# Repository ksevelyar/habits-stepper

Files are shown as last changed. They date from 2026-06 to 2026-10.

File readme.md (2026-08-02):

# Habits Stepper
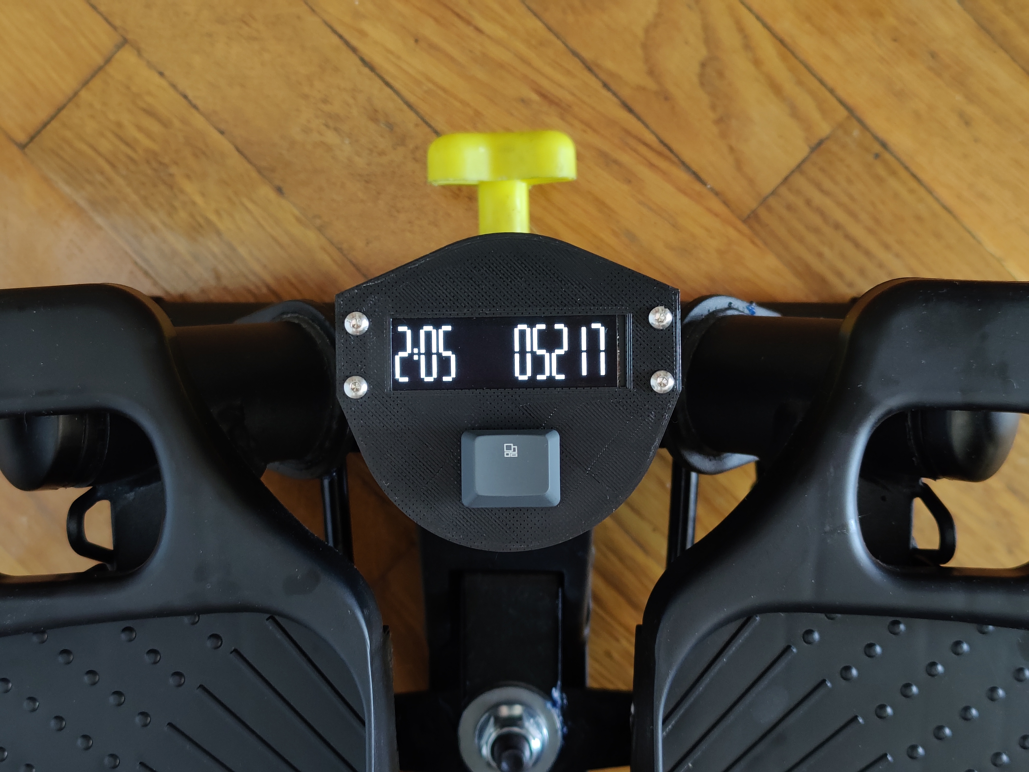
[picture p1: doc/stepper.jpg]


## Why
Automatically tracks stepping sessions without requiring any button presses to start or reset workouts. Time is synced via NTP so new day and week boundaries are handled automatically — no need to remember to reset counts on Monday. Just start stepping and sessions are tracked correctly.

## Overview
* auto-track stepping sessions, time-synced via NTP with a compile-time IANA timezone
* async embassy runtime; display updates only on input events via channels
* deep sleep after 90s of inactivity; 18650 battery gives ~2 weeks without charging
* firmware upload (probe-rs), defmt logs (RTT), and battery charging over a single USB-C port
* ring buffer in NOR flash (512 sessions); data survives deep sleep and reboots
* on-MCU tests via embedded_test
* 3D-printed case (OpenSCAD) with SH1122 256x64 OLED display

## Build & Flash
```
nix develop

cargo run --release
    Finished `release` profile [optimized + debuginfo] target(s) in 0.10s
     Running `probe-rs run --chip=esp32c3 --preverify --always-print-stacktrace --no-location target/riscv32imc-unknown-none-elf/release/habits-stepper`
    Verifying ✔ 100% [####################] 360.25 KiB @  74.20 KiB/s (took 5s)           Finished in 5.09s
03:00:00 [INFO ] init: embassy initialized
03:00:00 [INFO ] storage: flash capacity: 4194304B
03:00:00 [INFO ] storage: loaded 18 sessions from flash (head=18)
13:57:03 [INFO ] time: rtc seeded: Europe/Moscow 2026-06-13 13:57:03
13:57:03 [INFO ] wifi: connecting to "fellowship-of-the-ring-2"
13:57:04 [INFO ] wifi: connected to "fellowship-of-the-ring-2"
13:57:18 [INFO ] time: synced (+4s)
13:57:18 [INFO ] time: Europe/Moscow 2026-06-13 13:57:18
13:57:18 [INFO ] time: waiting 90s for inactivity
13:57:26 [INFO ] input: reed closed
13:57:26 [INFO ] time: activity before timeout, resetting
13:57:26 [INFO ] time: waiting 90s for inactivity
13:57:26 [INFO ] display: session update: today=50min(1036steps) week=50min
13:57:29 [INFO ] input: reed closed
13:57:29 [INFO ] time: activity before timeout, resetting
13:57:29 [INFO ] time: waiting 90s for inactivity
13:57:29 [INFO ] display: session update: today=50min(1037steps) week=50min
```

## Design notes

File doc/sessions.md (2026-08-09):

# Sessions
## Overview
Session task receives events from user_input, manages
session state, and sends session events to display.

## Input
* `StepDetected`: creates or prolongs current session
* `HistoryPressed`: switches display to SessionHistory view
* `HistoryReleased`: switches display back to SessionUpdate view

## Output
* `SessionEvent::Update(WeekTotals { minutes, steps })`: sent on step or history toggle
* `SessionEvent::History(WeekTotals { minutes, steps })`: sent on HistoryPressed

## Permanent storage
* Load sessions from permanent storage, log error on failure
* On load, log the number of loaded sessions
* On session end, save to permanent storage, signal today and yesterday totals for the backend, and log
* Backend replaces the value for a given date, so lost or failed posts self-heal on the next session end
* esp32c3 NOR flash wear should be minimized
* See [sessions/storage.md](sessions/storage.md) for the storage design

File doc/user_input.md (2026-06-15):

# User input

## Reed switch
A single reed switch on the right side captures both left and right steps. The pedals work in opposition: pressing the left pedal raises the right pedal, opening the reed and counting a left step; pressing the right pedal closes the reed and counts a right step. Both edges are counted as `StepDetected`.

## History button
When pressed the display shows the previous week's totals; when
released it returns to the current week.

## Boot
On boot, user_input sends `HistoryReleased` so the display shows data immediately.

## Sleep
* mcu wakes up from deep sleep via reed switch or history button
* deep sleep after 90s of inactivity
* the reed current level is sampled before sleep. Wake-up is set for the opposite level. This way the chip wakes on the first reed change whether the pedal was pressed or released at sleep time.

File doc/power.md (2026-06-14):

## Power
* Samsung ICR18650-26J 2600mAh
* tp4057
* mcp1700

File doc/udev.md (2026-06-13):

# udev setup for ESP32-C3 with probe-rs

```nix
services.udev.extraRules = ''
  SUBSYSTEM=="usb", ATTR{idVendor}=="303a", ATTR{idProduct}=="1001", MODE="0660", GROUP="dialout"
'';
```

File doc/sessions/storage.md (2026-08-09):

# Session Storage

`FlashRing` stores completed sessions in two 4096-byte NOR flash sectors.

| Sector | Address |
| --- | --- |
| 0 | `0x3F0000` |
| 1 | `0x3F1000` |

Each sector contains 256 slots. Each slot is 16 bytes:

| Offset | Size | Field |
| --- | --- | --- |
| 0 | 4 | Start epoch |
| 4 | 4 | End epoch |
| 8 | 4 | Steps |
| 12 | 4 | Unused |

Fields use little-endian encoding. An erased start epoch of `0xFFFF_FFFF` marks an empty slot.

On startup, storage scans the start epochs, counts occupied slots, and places the write position at the first empty slot. Sessions are returned from oldest to newest.

When 511 sessions are stored, storage erases the sector containing the oldest sessions before writing the next session. This removes 256 sessions.

Flash read, write, and erase failures are logged. Operations continue after failure.

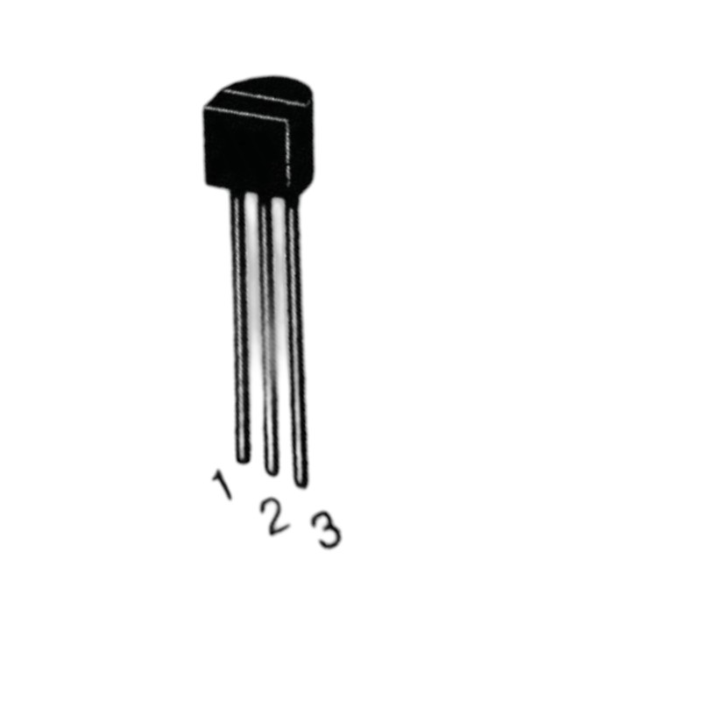
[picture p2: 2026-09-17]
doc/mcp1700.jpg

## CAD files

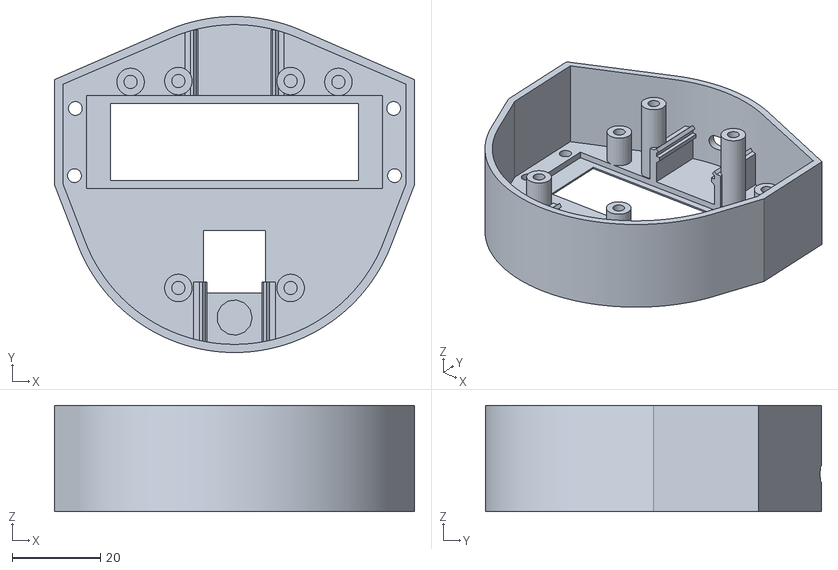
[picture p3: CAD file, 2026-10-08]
case/case.stl
81.5 x 76.0 x 24.0

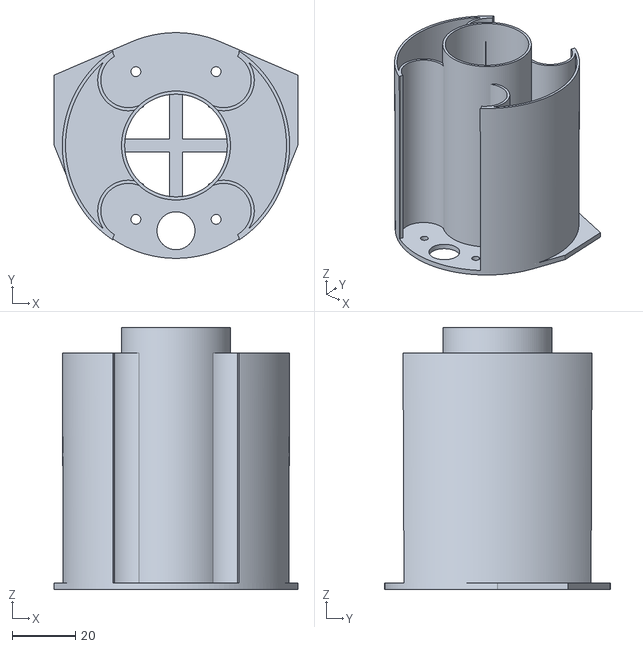
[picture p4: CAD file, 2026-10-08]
case/battery-holder.stl
77.2 x 71.5 x 83.0

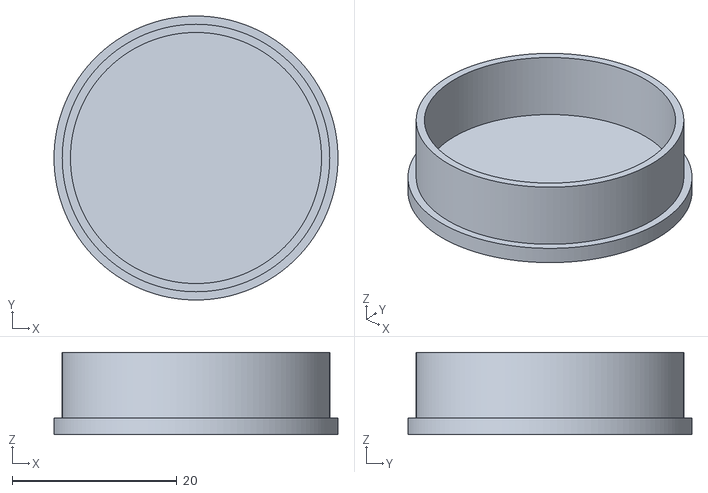
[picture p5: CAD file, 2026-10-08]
case/battery-cap.stl
34.5 x 34.5 x 10.0

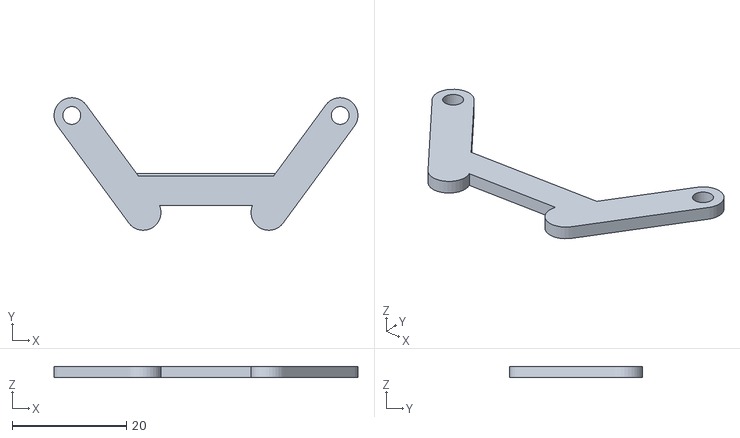
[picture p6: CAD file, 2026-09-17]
case/mcu-stopper.stl
53.2 x 23.2 x 2.00

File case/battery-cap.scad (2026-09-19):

include <mixin.scad>;

battery_cap_height = 8;

difference() {
  union() {
    translate([0, 0, 0]) cylinder(h=battery_cap_height + wall, d=battery_slot_diameter, center=false, $fn=128);
    translate([0, 0, 0]) cylinder(h=wall, d=battery_slot_diameter + 2, center=false, $fn=128);
  }

  translate([0, 0, wall]) cylinder(h=100, d=battery_slot_diameter - 2, center=false, $fn=128);
}

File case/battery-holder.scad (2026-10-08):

include <mixin.scad>;

height = 85;
connector_inner_diameter = 17.4;
mounting_hole_diameter = 3.12;

module walls() {
  difference() {
    translate([0, 0, wall]) cylinder(h=height - 12, d1=diameter - 0.5, d2=diameter, $fn=256);
    translate([0, 0, -overcut]) cylinder(h=height * 2, d=diameter - wall, $fn=256);

    translate([-20, -40, 0]) cube(size=[40, 100, height + overcut], center=false);
  }

  difference() {
    union() {
      translate([15.1, -20.7, 0]) rotate([0, 0, -60]) walls_connector();

      translate([15.1, 20.7, 0]) rotate([0, 0, -120]) walls_connector();
      translate([-15.1, 20.7, 0]) rotate([0, 0, 120]) walls_connector();
      translate([-15.1, -20.7, 0]) rotate([0, 0, 60]) walls_connector();
    }
  }
}

module walls_connector() {
  difference() {
    translate([0, 0, wall]) cylinder(h=height - 12, d=connector_inner_diameter + wall, $fn=256);
    translate([0, 0, -overcut]) cylinder(h=height * 2, d=connector_inner_diameter, $fn=256);

    translate([-(connector_inner_diameter + wall) / 2, -connector_inner_diameter, 0])
      cube([connector_inner_diameter + wall, connector_inner_diameter, height + overcut], center=false);
  }
}

module battery() {
  difference() {
    union() {
      difference() {
        hull() {
          length = display_length + 0.2;
          width = display_pcb_width + 3.1;
          translate([-length / 2, 0, 0]) cube(size=[length, width, wall]);

          translate([0, 0, 0]) cylinder(h=wall, d=diameter - 0.5, $fn=128);
        }

        translate([0, -27, -1]) cylinder(h=wall * 2, d=12, $fn=128);
      }
      translate([0, 0, 0]) cylinder(h=height - wall, d=battery_slot_diameter + 2, center=false, $fn=128);
    }

    translate([0, 0, -overcut]) cylinder(h=height + overcut, d=battery_slot_diameter, center=false, $fn=128);

    mounting_holes();
  }
}

module mounting_holes() {
  translate([12.7, -23.4, -overcut]) cylinder(h=wall * 2, d=mounting_hole_diameter, $fn=32);
  translate([-12.7, -23.4, -overcut]) cylinder(h=wall * 2, d=mounting_hole_diameter, $fn=32);
  translate([12.7, 23.4, -overcut]) cylinder(h=wall * 2, d=mounting_hole_diameter, $fn=32);
  translate([-12.7, 23.4, -overcut]) cylinder(h=wall * 2, d=mounting_hole_diameter, $fn=32);
}

module cross() {
  translate([-wall, -20, 0]) cube([wall*2, 40, wall]);
  translate([-20, -wall, 0]) cube([40, wall*2, wall]);
}

cross();

battery();
walls();

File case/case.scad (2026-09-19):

include <mixin.scad>;

height = 24;

module charger_led_cutout() {
  translate([0, -30.1, 0.2]) cylinder(h=wall, d=8);
}

module display_cutout() {
  display_slot_cutout();
  display_window_cutout();
}

module mounts() {
  translate([12.7, -23.4, 0]) leg(height - wall);
  translate([-12.7, -23.4, 0]) leg(height - wall);

  translate([12.7, 23.4, 0]) leg(height - wall);
  translate([-12.7, 23.4, 0]) leg(height - wall);

  translate([display_length / 2 - 15, display_pcb_width + 4, 0]) leg(10);
  translate([-display_length / 2 + 15, display_pcb_width + 4, 0]) leg(10);
}

difference() {
  union() {
    display();
    esp32c3_mini_rails();
    tp4057_rails();
    mounts();
  }

  type_c_cutout();
  button_cutout();
  charger_led_cutout();
  display_cutout();

  translate([display_length / 2 - 2.3, 2, -overcut]) cylinder(h=wall * 2, d=3.12, $fn=64, center=false);
  translate([-display_length / 2 + 2.3, 2, -overcut]) cylinder(h=wall * 2, d=3.12, $fn=64, center=false);
  translate([display_length / 2 - 2.5, display_pcb_width - 2, -overcut]) cylinder(h=wall * 2, d=3.12, $fn=64, center=false);
  translate([-display_length / 2 + 2.5, display_pcb_width - 2, -overcut]) cylinder(h=wall * 2, d=3.12, $fn=64, center=false);
}

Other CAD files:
case/mcu-stopper.scad
case/mixin.scad

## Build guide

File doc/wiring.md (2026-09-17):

# Wiring

## charging (tp4057)
5v from esp32 to in+
gnd from esp32 to in-

bat- to 18650-
bat+ to 18650+

out- to gnd from esp32
out+ - mcp1700 1 - esp32 3.3v

## mcp1700
1 - gnd
2 - tp4057 out+
3 - esp32 3.3v

## display sh1122, spi
gnd - gnd
vdd - 3v3
scl - gpio5
sda - gpio6
rst - gpio7
dc  - gpio9
cs  - gpio10

## buttons
reed - gpio1 + gnd
history - gpio2 + gnd

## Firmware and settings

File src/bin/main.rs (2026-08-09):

#![no_std]
#![no_main]

use esp_alloc as _;
use esp_hal::{
    clock::CpuClock,
    gpio::{Input, InputConfig, Level, Output, OutputConfig, Pull},
    rtc_cntl::Rtc,
    spi::Mode,
    spi::master::{Config as SpiConfig, Spi},
    time::Rate,
    timer::timg::TimerGroup,
};
use habits_stepper::sessions::FlashMutex;
use habits_stepper::sessions::storage;
use habits_stepper::{display, sessions, sync, time, user_input, wifi};
use panic_rtt_target as _;

use defmt::info;
use embassy_executor::Spawner;
use embassy_sync::mutex::Mutex;
use embassy_time::{Duration, Timer};
use static_cell::StaticCell;

extern crate alloc;

esp_bootloader_esp_idf::esp_app_desc!();

#[esp_rtos::main]
async fn main(spawner: Spawner) -> ! {
    rtt_target::rtt_init_defmt!();

    let config = esp_hal::Config::default().with_cpu_clock(CpuClock::max());
    let peripherals = esp_hal::init(config);
    let rtc = Rtc::new(peripherals.LPWR);

    esp_alloc::heap_allocator!(#[esp_hal::ram(reclaimed)] size: 66320);

    let timg0 = TimerGroup::new(peripherals.TIMG0);
    let sw_interrupt =
        esp_hal::interrupt::software::SoftwareInterruptControl::new(peripherals.SW_INTERRUPT);
    esp_rtos::start(timg0.timer0, sw_interrupt.software_interrupt0);
    info!("init: embassy initialized");

    let (controller, stack, runner) = wifi::init(peripherals.WIFI).await;

    spawner.spawn(wifi::connection(controller).unwrap());
    spawner.spawn(wifi::net_task(runner).unwrap());
    let rtc = time::RTC.init(Mutex::new(rtc));
    spawner.spawn(time::ntp_task(stack, rtc).unwrap());
    spawner.spawn(time::sleep_task(rtc).unwrap());
    spawner.spawn(sync::sync_task(stack).unwrap());
    let display_spi = Spi::new(
        peripherals.SPI2,
        SpiConfig::default()
            .with_frequency(Rate::from_mhz(4))
            .with_mode(Mode::_0),
    )
    .unwrap()
    .with_sck(peripherals.GPIO5)
    .with_mosi(peripherals.GPIO6);

    let display_cs = Output::new(peripherals.GPIO10, Level::High, OutputConfig::default());
    let display_dc = Output::new(peripherals.GPIO9, Level::Low, OutputConfig::default());
    let display_rst = Output::new(peripherals.GPIO7, Level::High, OutputConfig::default());

    let reed = Input::new(
        peripherals.GPIO1,
        InputConfig::default().with_pull(Pull::Up),
    );
    let history = Input::new(
        peripherals.GPIO2,
        InputConfig::default().with_pull(Pull::Up),
    );

    spawner.spawn(user_input::reed_task(reed).unwrap());
    spawner.spawn(user_input::history_task(history).unwrap());
    spawner.spawn(display::display_task(display_spi, display_cs, display_dc, display_rst).unwrap());
    static FLASH_RING: StaticCell<FlashMutex> = StaticCell::new();
    let flash_mutex = FLASH_RING.init(Mutex::new(storage::FlashRing::new(peripherals.FLASH)));

    spawner.spawn(sessions::session_task(flash_mutex).unwrap());

    loop {
        Timer::after(Duration::from_secs(3600)).await;
    }
}

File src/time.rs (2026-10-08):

use core::net::{IpAddr, SocketAddr};
use core::sync::atomic::{AtomicU32, Ordering};
use embassy_time::with_timeout;
use esp_hal::gpio::RtcPinWithResistors;
use esp_hal::peripherals::GPIO;
use esp_hal::rtc_cntl::sleep::{RtcioWakeupSource, WakeupLevel};

use defmt::{error, info, warn};
use embassy_net::{
    Stack,
    dns::DnsQueryType,
    udp::{PacketMetadata, UdpSocket},
};
use embassy_sync::blocking_mutex::raw::CriticalSectionRawMutex;
use embassy_sync::mutex::Mutex;
use embassy_time::{Duration, Instant, Timer};

use crate::user_input::ACTIVITY;
use esp_hal::rtc_cntl::Rtc;
use jiff::Timestamp;
use jiff::civil::Weekday;
use static_cell::StaticCell;

include!(concat!(env!("OUT_DIR"), "/timezone.rs"));

use sntpc::{NtpContext, NtpTimestampGenerator, get_time};
use sntpc_net_embassy::UdpSocketWrapper;

const NTP_SERVER: &str = "pool.ntp.org";
const MIN_VALID_EPOCH: u32 = 1_700_000_000;
const USEC_IN_SEC: u64 = 1_000_000;
const INACTIVITY: Duration = Duration::from_secs(120);

static EPOCH_BASE: AtomicU32 = AtomicU32::new(0);
static INSTANT_BASE: AtomicU32 = AtomicU32::new(0);
static INSTANT_MILLIS_BASE: AtomicU32 = AtomicU32::new(0);

pub static RTC: StaticCell<Mutex<CriticalSectionRawMutex, Rtc<'static>>> = StaticCell::new();

defmt::timestamp!(
    "{}",
    LocalTime {
        zoned: local_time(),
        tenth_of_second: tenth_of_second(),
    }
);

pub fn epoch_secs() -> Option<u32> {
    let base = EPOCH_BASE.load(Ordering::Acquire);
    if base == 0 {
        return None;
    }
    let now = Instant::now().as_secs();
    let ibase = INSTANT_BASE.load(Ordering::Relaxed) as u64;
    let delta = now.saturating_sub(ibase) as u32;
    Some(base + delta)
}

pub fn week_start_epoch(now: u32) -> u32 {
    let timestamp = jiff::Timestamp::new(now as i64, 0).unwrap();
    let zoned = timestamp.to_zoned(TIMEZONE);
    let since_monday = zoned.weekday().since(Weekday::Monday);
    let monday = zoned.saturating_sub(jiff::Span::new().days(since_monday as i64));
    let midnight = monday.saturating_sub(
        jiff::Span::new()
            .hours(monday.hour() as i64)
            .minutes(monday.minute() as i64)
            .seconds(monday.second() as i64),
    );
    midnight.timestamp().as_second() as u32
}

pub fn day_start_epoch(now: u32) -> u32 {
    let timestamp = jiff::Timestamp::new(now as i64, 0).unwrap();
    let midnight = timestamp.to_zoned(TIMEZONE).start_of_day().unwrap();
    midnight.timestamp().as_second() as u32
}

pub fn next_day_start_epoch(day_start: u32) -> u32 {
    let timestamp = jiff::Timestamp::new(day_start as i64, 0).unwrap();
    let next = timestamp
        .to_zoned(TIMEZONE)
        .saturating_add(jiff::Span::new().days(1));
    next.start_of_day().unwrap().timestamp().as_second() as u32
}

pub fn previous_day_start_epoch(now: u32) -> u32 {
    let timestamp = jiff::Timestamp::new(now as i64, 0).unwrap();
    let yesterday = timestamp
        .to_zoned(TIMEZONE)
        .saturating_sub(jiff::Span::new().days(1));
    yesterday.start_of_day().unwrap().timestamp().as_second() as u32
}

pub fn date_bytes(now: u32) -> [u8; 10] {
    let timestamp = jiff::Timestamp::new(now as i64, 0).unwrap();
    let zoned = timestamp.to_zoned(TIMEZONE);
    let mut buf = [0u8; 10];
    write_digits(&mut buf[0..4], zoned.year() as u32);
    buf[4] = b'-';
    write_digits(&mut buf[5..7], zoned.month() as u32);
    buf[7] = b'-';
    write_digits(&mut buf[8..10], zoned.day() as u32);
    buf
}

fn write_digits(buf: &mut [u8], mut value: u32) {
    for byte in buf.iter_mut().rev() {
        *byte = b'0' + (value % 10) as u8;
        value /= 10;
    }
}

fn tenth_of_second() -> u8 {
    if EPOCH_BASE.load(Ordering::Acquire) == 0 {
        return 0;
    }
    let now_millis = Instant::now().as_millis() as u32;
    let base_millis = INSTANT_MILLIS_BASE.load(Ordering::Relaxed);
    let subsec_millis = now_millis.wrapping_sub(base_millis) % 1000;
    (subsec_millis / 100) as u8
}

struct LocalTime {
    zoned: jiff::Zoned,
    tenth_of_second: u8,
}

impl defmt::Format for LocalTime {
    fn format(&self, formatter: defmt::Formatter) {
        defmt::write!(
            formatter,
            "{=u8:02}:{=u8:02}:{=u8:02}.{=u8}",
            self.zoned.hour() as u8,
            self.zoned.minute() as u8,
            self.zoned.second() as u8,
            self.tenth_of_second,
        );
    }
}

fn local_time() -> jiff::Zoned {
    let epoch_secs = epoch_secs().unwrap_or(0);
    let timestamp = jiff::Timestamp::new(epoch_secs as i64, 0).unwrap();

    timestamp.to_zoned(crate::time::TIMEZONE)
}

fn set_epoch(epoch_secs: u32) {
    INSTANT_BASE.store(Instant::now().as_secs() as u32, Ordering::Relaxed);
    INSTANT_MILLIS_BASE.store(Instant::now().as_millis() as u32, Ordering::Relaxed);
    EPOCH_BASE.store(epoch_secs, Ordering::Release);
}

fn seed_from_rtc(rtc: &Rtc) {
    let us = rtc.current_time_us();
    let secs = (us / USEC_IN_SEC) as u32;
    if secs > MIN_VALID_EPOCH {
        set_epoch(secs);
        let ts = Timestamp::new(secs as i64, 0).unwrap();
        let z = ts.to_zoned(TIMEZONE);
        info!(
            "time: rtc seeded: {=str} {=i16}-{=i8:02}-{=i8:02} {=i8:02}:{=i8:02}:{=i8:02}",
            TIMEZONE.iana_name().unwrap(),
            z.year(),
            z.month(),
            z.day(),
            z.hour(),
            z.minute(),
            z.second()
        );
    }
}

fn log_sync(correction: Option<i64>) {
    let corr = correction.unwrap_or(0);
    if corr >= 0 {
        info!("time: synced (+{=i64}s)", corr);
    } else {
        info!("time: synced ({=i64}s)", corr);
    }

    if let Some(epoch) = epoch_secs() {
        let ts = Timestamp::new(epoch as i64, 0).unwrap();
        let z = ts.to_zoned(TIMEZONE);
        info!(
            "time: {=str} {=i16}-{=i8:02}-{=i8:02} {=i8:02}:{=i8:02}:{=i8:02}",
            TIMEZONE.iana_name().unwrap(),
            z.year(),
            z.month(),
            z.day(),
            z.hour(),
            z.minute(),
            z.second()
        );
    }
}

#[derive(Clone, Copy)]
struct NtpTs {
    current_time_us: u64,
}

impl NtpTimestampGenerator for NtpTs {
    fn init(&mut self) {}
    fn timestamp_sec(&self) -> u64 {
        self.current_time_us / USEC_IN_SEC
    }
    fn timestamp_subsec_micros(&self) -> u32 {
        (self.current_time_us % USEC_IN_SEC) as u32
    }
}
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

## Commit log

2026-05-11 implement permanent sessions with nvs ring buffer
    [case.scad]
2026-05-12 fix hours rendering, display workout minutes for today and for current week
    [display.rs, main.rs, sessions.rs]
2026-05-16 add case
    [case.scad]
2026-05-17 case: fix esp32 position, use diffuser for display
    [case.scad, case.stl]
2026-05-19 abstract gpio switches, improve case
    [battery-holder.scad, battery-holder.stl, case.scad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]
2026-05-20 case: fix rails and display slot
    [battery-holder.scad, battery-holder.stl, case.scad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]
2026-05-26 add doc/wiring.md
    [battery-holder.scad, battery-holder.stl, case.stl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]
2026-05-26 improve display cutout
    [case.scad]
2026-05-29 add tp4057 to wiring
    [case.stl]
2026-05-30 fix reed switch
2026-06-07 rewrite to async embassy tasks
    [case.scad]
2026-06-07 update case
    [case.scad]
2026-06-07 clean deps with cargo-udeps
    [case.scad, debug.stl]
2026-06-09 add mcu stopper, simplify wiring
    [case.stl, debug.stl, mcu-stopper.scad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]
2026-06-09 rewrite user_input with interrupt-driven debounce
2026-06-09 case fixes
    [battery-holder.scad, battery-holder.stl, case.scad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]
2026-06-09 case: extract shared scad to mixin
    [battery-holder.scad, case.scad, debug.scad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]
2026-06-12 case: add parametric height for rail(); add battery-cap
    [battery-cap.scad, battery-cap.stl, battery-holder.scad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]
2026-06-13 release 1.0.0: add photo, align steps by display width, show 2-week history
    [battery-cap.scad, battery-cap.stl, battery-holder.scad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]
2026-06-14 count all steps with one reed switch
2026-06-15 sample reed gpio before deep sleep to avoid immediate wake when reed is closed
    [time.rs]
2026-08-02 update readme with photo of new case
2026-08-06 case: improve battery cap
    [battery-cap.scad, battery-cap.stl]
2026-08-09 remove redundant SlotFlags
2026-08-09 fix first step render
    [sessions.rs]
2026-09-16 case: refactor display cutout
    [battery-holder.scad, case.scad, case.stl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]
2026-09-17 increase display slot in case.scad, improve docs on mcp1700
    [case.scad, case.stl, mcu-stopper.scad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]
2026-09-19 case: reduce battery slot, use overcut for cutter clearance
    [battery-cap.scad, battery-holder.scad, battery-holder.stl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]
2026-09-20 add regenerate-stl
    [battery-cap.scad, battery-cap.stl, battery-holder.scad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]
2026-09-22 case: update battery cap
    [battery-cap.scad, battery-cap.stl, battery-holder.stl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]
2026-10-01 case: make tp4057 parametric
    [mixin.scad]
2026-10-08 sync only if METRICS_URL set
    [mixin.scad]
2026-10-08 openscad -> openscad-unstable
    [battery-cap.stl, battery-holder.stl, case.stl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]
